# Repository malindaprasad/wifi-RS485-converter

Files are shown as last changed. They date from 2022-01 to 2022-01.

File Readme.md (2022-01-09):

## Simple RS485 to WiFi Converter. 

This include ESP8266 WiFi Module, RS485 TTL Converter and 220V to 5V HiLink power supply. so simply can plug to main power

හුග දෙනෙක් Offgrid සොලර් ගහන නිසා  කලින් කරපු මේ PCB එක ශෙයා කරන්න හිතුන. පරිපථ හැදුවට මම PCB අදින්න වැඩිය දන්නෙ නැ. මිතුරකුගෙ සහයෙන් ඇදල JL PCB එකෙන් හදවල ගෙනාව. දැනට වසර කීපයක් ගැටලුවක් නැතිව Hybrid Inverter හා Easton SDM 120, SDM230 එක්ක ගැටලුවක් නැතිව ඩිවයිස් කීපයක් වැඩ. මෙයා කරන්නෙ ModBus එකෙන් දත්ත ටික අරන මගෙ සර්වරයකට යවන එක.  හුග දෙනෙක් වයර් අමුනල කරල අන්තිමට පිලිවෙලක් කරගන්න හිතන නිසයි මේක දැම්මෙ 

කෙලින්ම 5V එකකට දෙනවනම් HiLink එක ඔ්නෙ නැ. 
Inverter හරි ඩිවයිස් එකේ RS485 to TCP Converter එකක් එනවනම්, RS485 TTL එක නැතිව WiFi වලින් ඇදල ගන්නත් පුලුවන්. මම ඒ විදිහට එක ඩිවයිස් එකක් ගන්නව

කාට හරි ප්‍රයෝජනයක් වෙයි. වෙනස් කලොත්.. ගැටලුවක් හැදුවොත් මටත් කියන්න

zip එක කෙලින්ම දෙන්න පුලුවන් Printing සයිට් එකට 

### PCB 
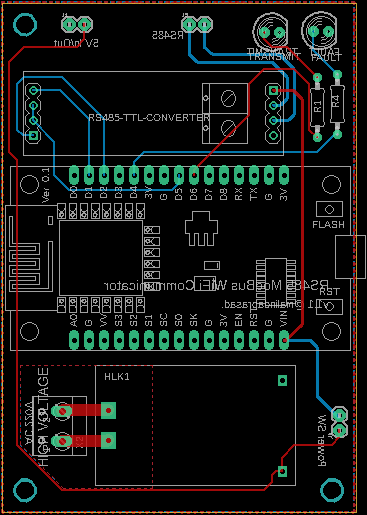
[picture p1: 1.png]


### Schematic 
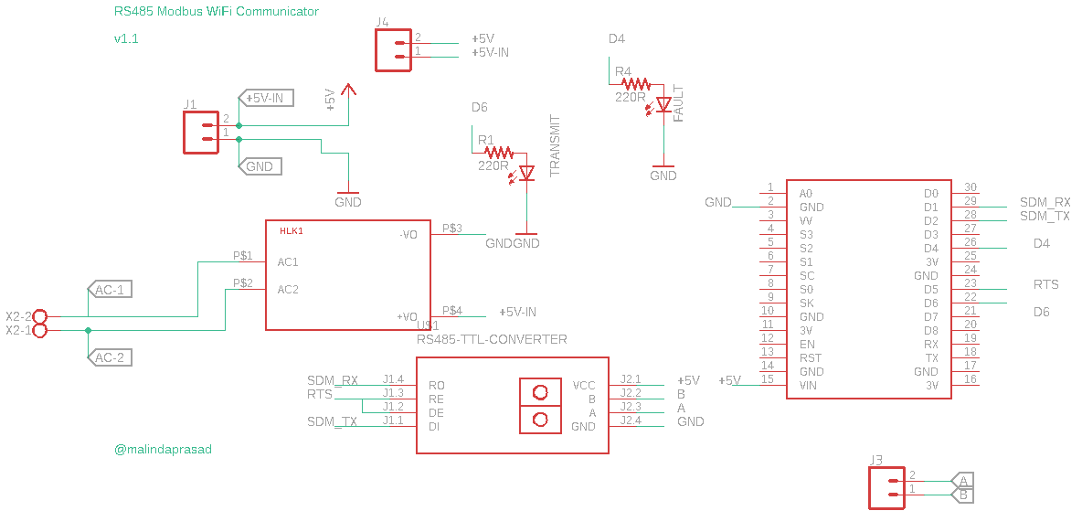
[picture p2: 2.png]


### Printed PCB
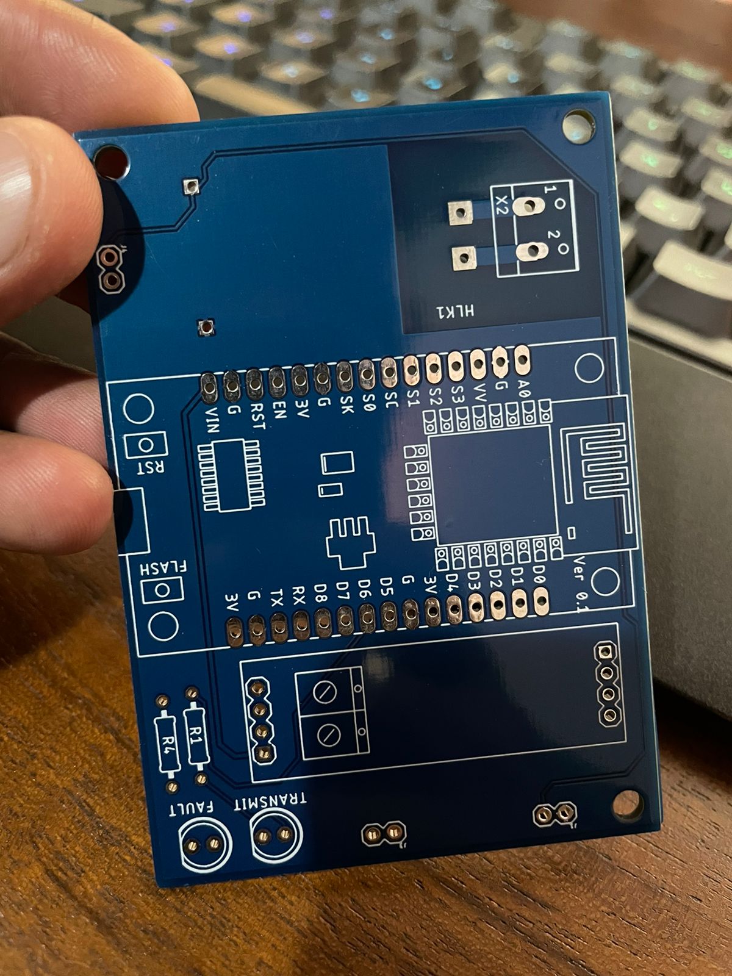
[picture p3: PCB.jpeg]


### Screens using data

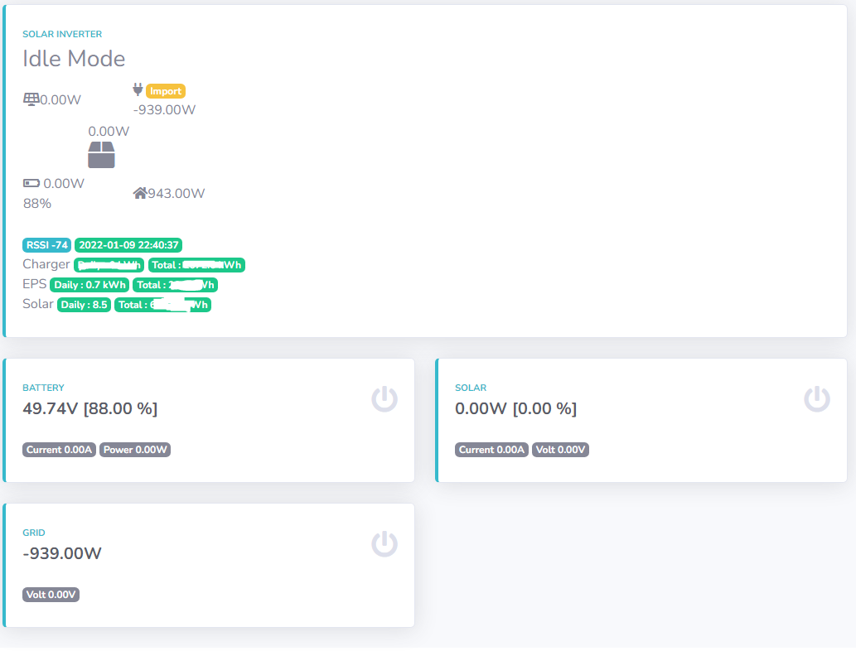
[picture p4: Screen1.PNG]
Screen

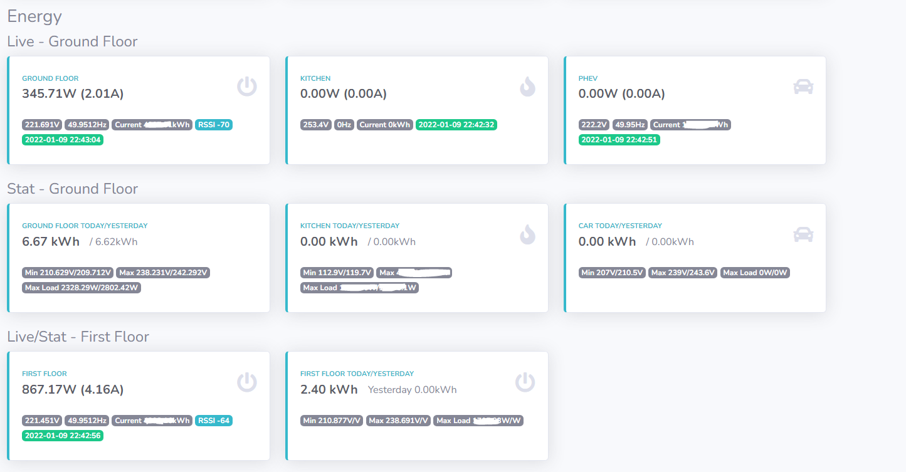
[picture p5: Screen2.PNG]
Screen

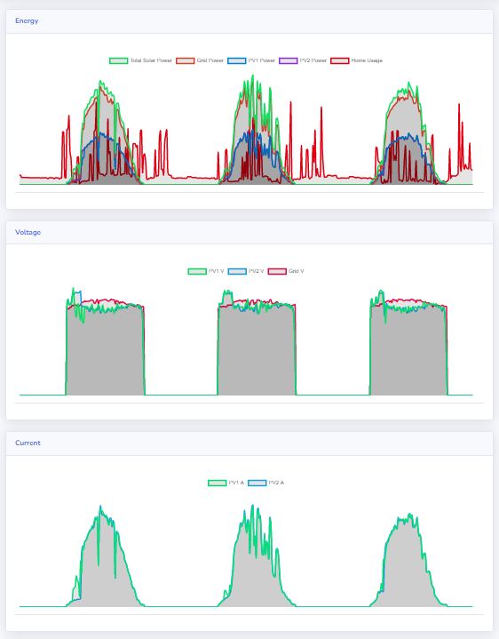
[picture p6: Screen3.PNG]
Screen

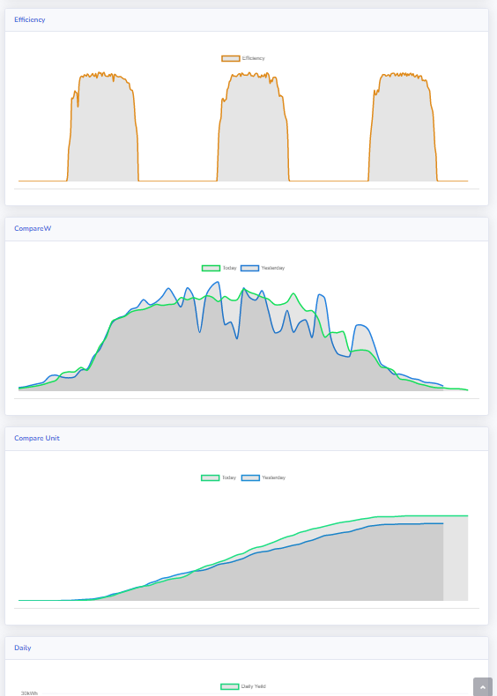
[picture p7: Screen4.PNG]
Screen


Support by
@danindudesilva

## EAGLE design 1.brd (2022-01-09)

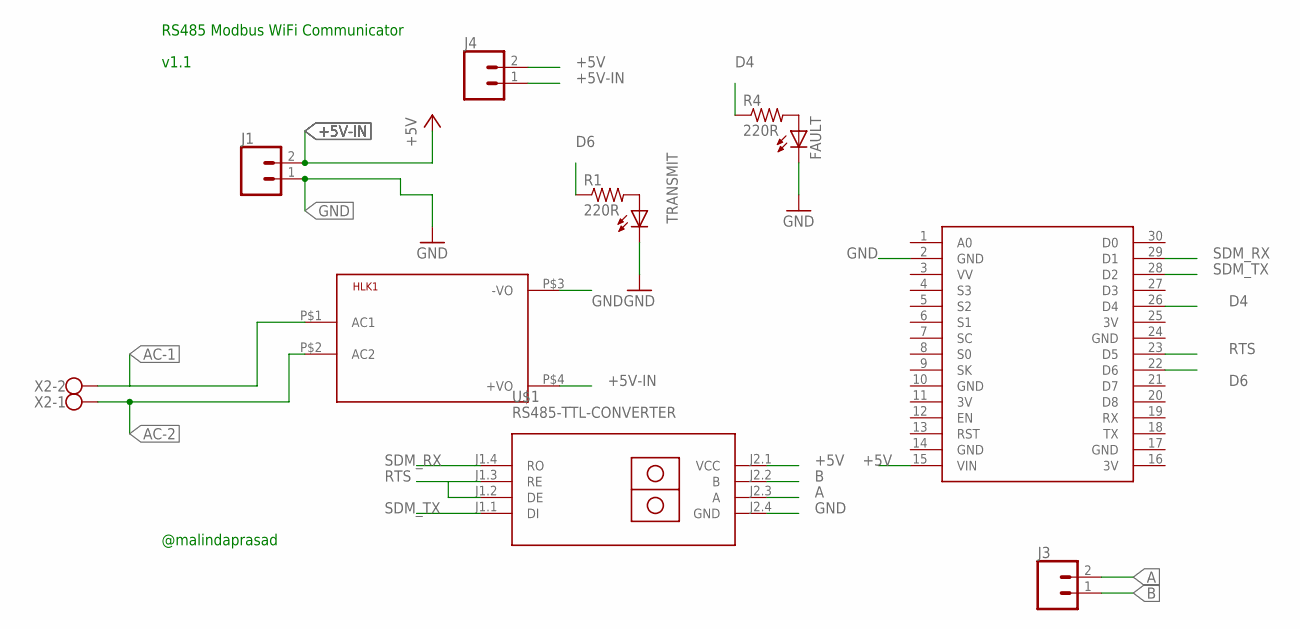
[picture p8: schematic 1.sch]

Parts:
FAULT: LED5MM
HLK1: HLK-PM013W; HLK-PM01
J1, J3, J4: CONN_02; 1X02
R1, R4: 220R; 0207/10
TRANSMIT: LED5MM
U$1: RS485-TTL-CONVERTER
U$2: NODEMCU
X2: W237-102

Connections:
3V: U$2.11 (3V), U$2.16 (3V), U$2.25 (3V)
+5V: J4.2, U$1.J2.1 (VCC), U$2.15 (VIN)
+5V-IN: HLK1.P$4 (+VO), J1.2, J4.1
A: J3.2, U$1.J2.3 (A)
AC-1: HLK1.P$1 (AC1), X2.2
AC-2: HLK1.P$2 (AC2), X2.1
B: J3.1, U$1.J2.2 (B)
D4: R4.1, U$2.26 (D4)
D6: R1.1, U$2.22 (D6)
GND: FAULT.K (C), HLK1.P$3 (-VO), J1.1, TRANSMIT.K (C), U$1.J2.4 (GND), U$2.2 (GND), U$2.10 (GND), U$2.14 (GND), U$2.17 (GND), U$2.24 (GND)
unnamed: R1.2, TRANSMIT.A
unnamed: FAULT.A, R4.2
RTS: U$1.J1.2 (DE), U$1.J1.3 (RE), U$2.23 (D5)
SDM_RX: U$1.J1.4 (RO), U$2.29 (D1)
SDM_TX: U$1.J1.1 (DI), U$2.28 (D2)

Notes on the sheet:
@malindaprasad
v1.1
RS485 Modbus WiFi Communicator

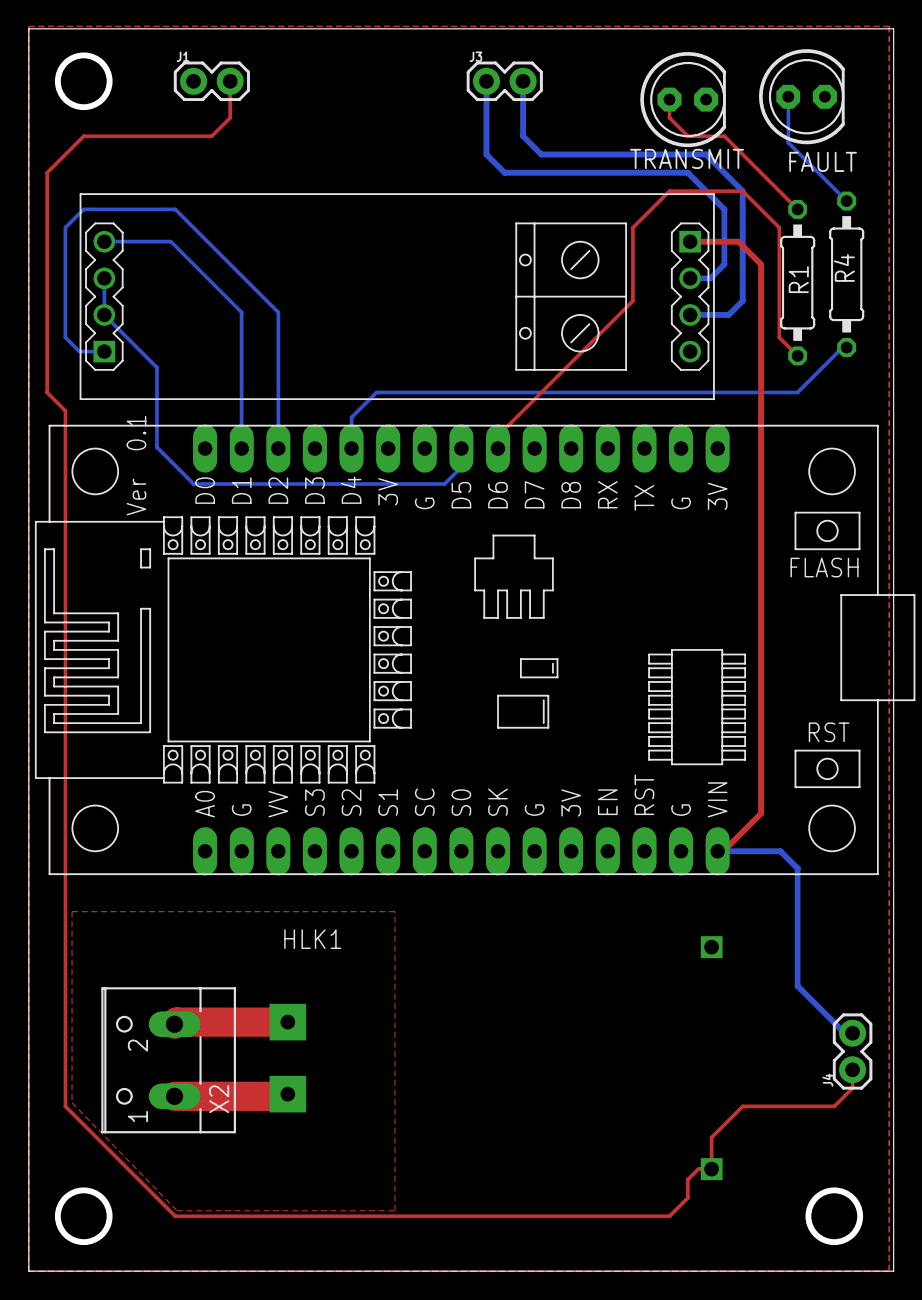
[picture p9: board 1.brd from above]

Board: 2 copper layers, 60.0 x 86.2 mm, 11 parts (0 on the bottom side), 15 nets.

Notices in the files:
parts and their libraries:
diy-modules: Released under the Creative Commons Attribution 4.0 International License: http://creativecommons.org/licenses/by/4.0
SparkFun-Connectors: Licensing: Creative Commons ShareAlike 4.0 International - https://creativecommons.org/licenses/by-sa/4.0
